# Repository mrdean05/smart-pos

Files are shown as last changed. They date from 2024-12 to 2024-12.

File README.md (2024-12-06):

<h2> Battery Powered Two-Layer PCB <h2>

__Note - This is an ongoing project__

## Introduction
This project describes the design and development of a battery-powered, two-layer PCB for a smart point-of-sale (POS) device. The smart point-of-sale device is intended to work with a barcode scanner, identifying items and products with barcode IDs. It comes with a TFT screen and a GUI displaying the product details, including the brand, type, weight, and cost.

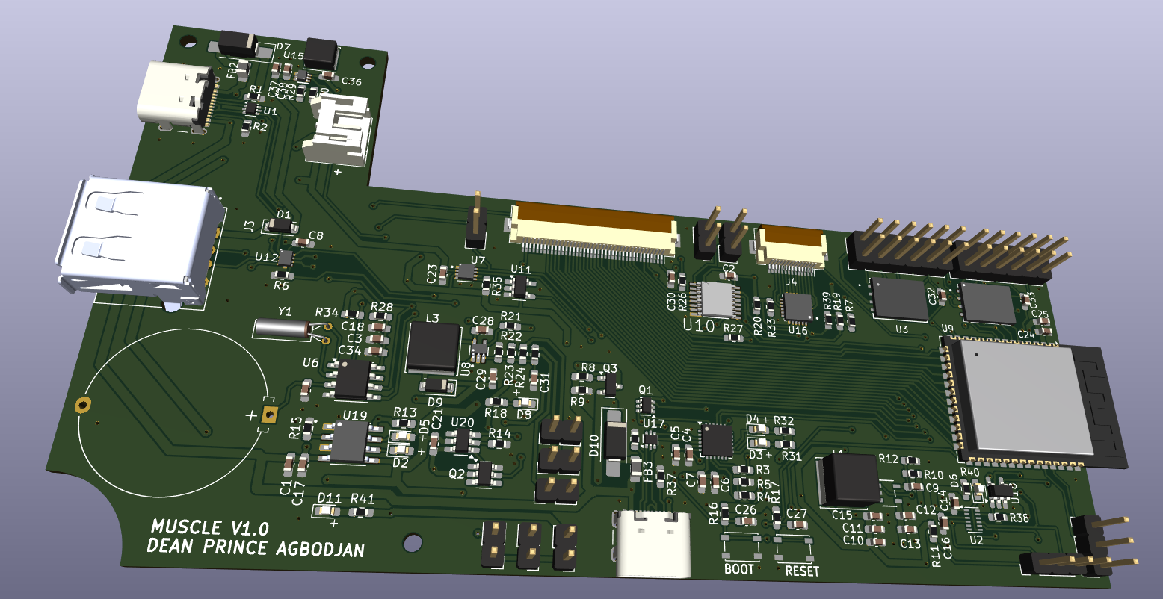
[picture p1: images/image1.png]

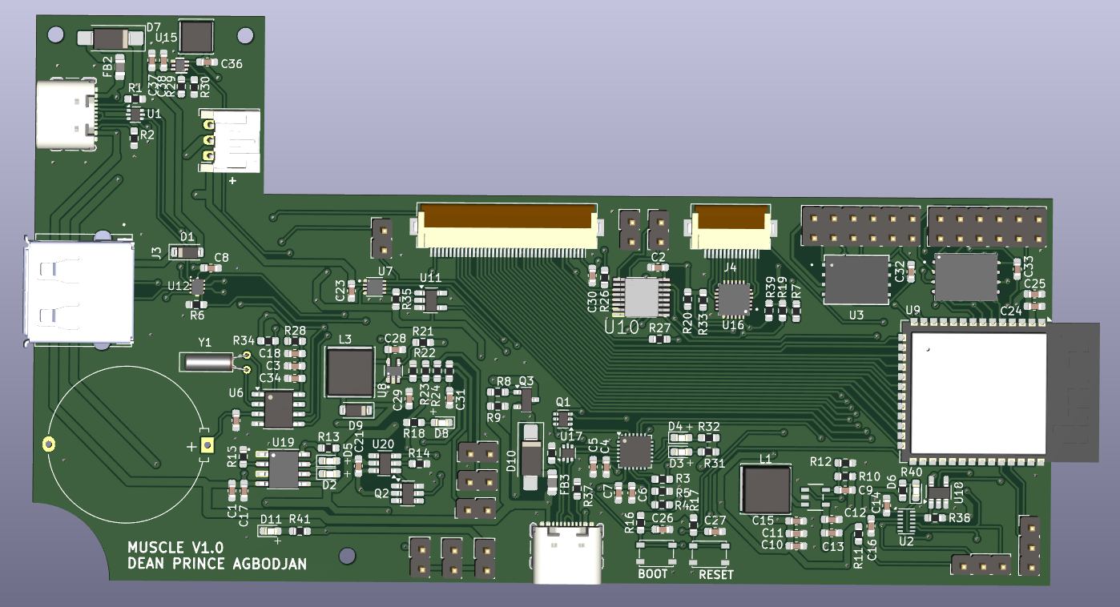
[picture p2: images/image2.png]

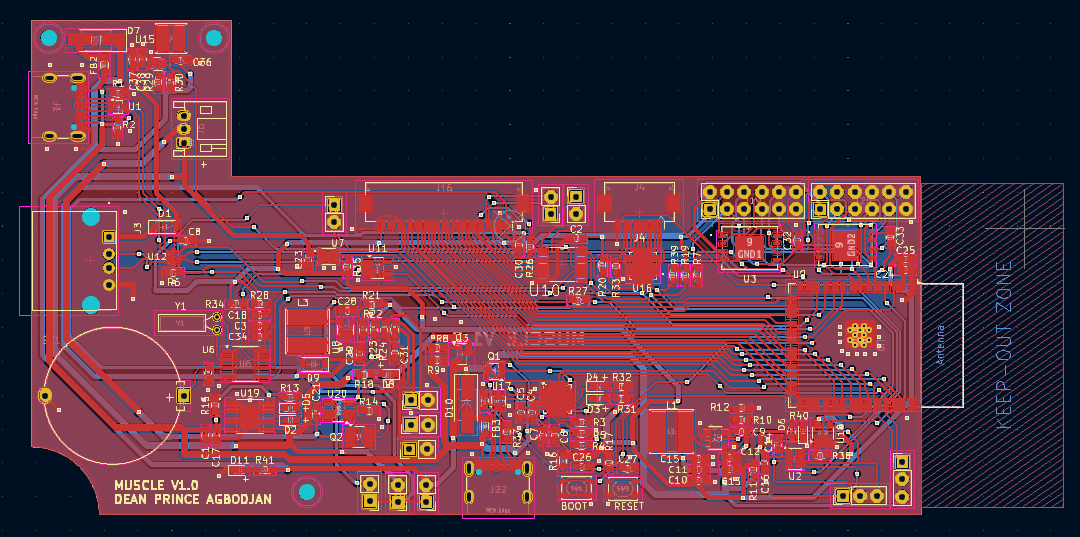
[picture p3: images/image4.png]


## Background of Project
There are numerous small to medium enterprises in Ghana that lack an effective way to track their inventory and finances. The existing implementations are very bulky and expensive, with software that is difficult for an average small shop owner to navigate, and with outrageous monthly subscriptions. This smart point-of-sale (POS) device seeks to simplify and improve the existing solution by creating a quick-to-use, cheap, and portable device. It works with a mobile application that updates the shop owner on every item bought in the shop, giving the shop owner visibility over their shop without their physical presence.

## Hardware and Circuit Design
The PCB was design and developed using KiCad. It comprises of multiple ICs (micocontroller, convertor ICs, and others).

* The Micrcontroller used is the ESP32s3. ESP32s3 is a System-On-Chip(SoC) integrating WiFi and Bluetooth, with peripherals that enable connection with other ICs and modules. 

* The PCBs also integrates ICs such
    - **SY8089 Buck Power Converter** that reduces the input voltage from 5V to 3.3V for the microcontroller and other components in the circuit. It has about 2A output current, with capacitors used as noise filters.
    - **TP4056 and DW01A** that ensure battery health safety by preventing under and over charging.
    - **MAX17048** as a current fuel gauge for the battery.
    - **PCF8523T** serves as an RTC module providing precise time and date information. It is supplied by a coin battery that ensures its continual performance when the device is off.
    - **TCA8418** serves as a keypad scan device through which users can interact with the POS device.
    - **W25N02KVZEIR and W25Q256JVEIQ** that serves as additional flash memory.
    - **PCA95548** serves as additional gpios.

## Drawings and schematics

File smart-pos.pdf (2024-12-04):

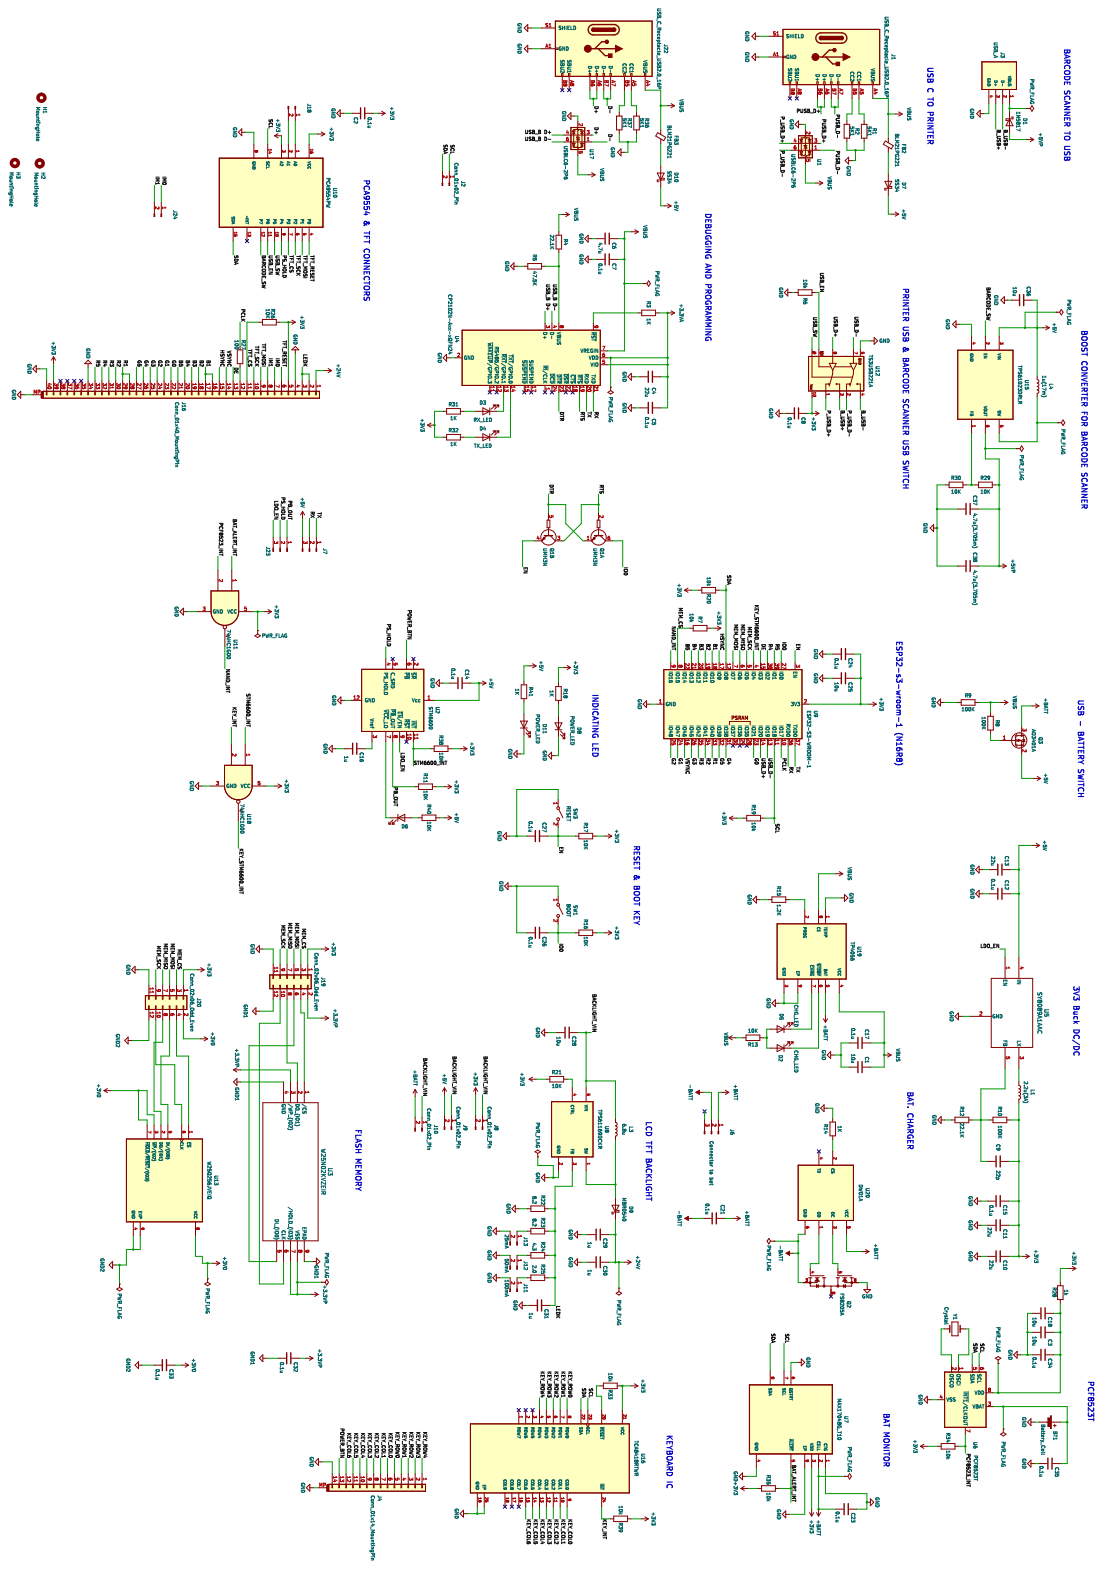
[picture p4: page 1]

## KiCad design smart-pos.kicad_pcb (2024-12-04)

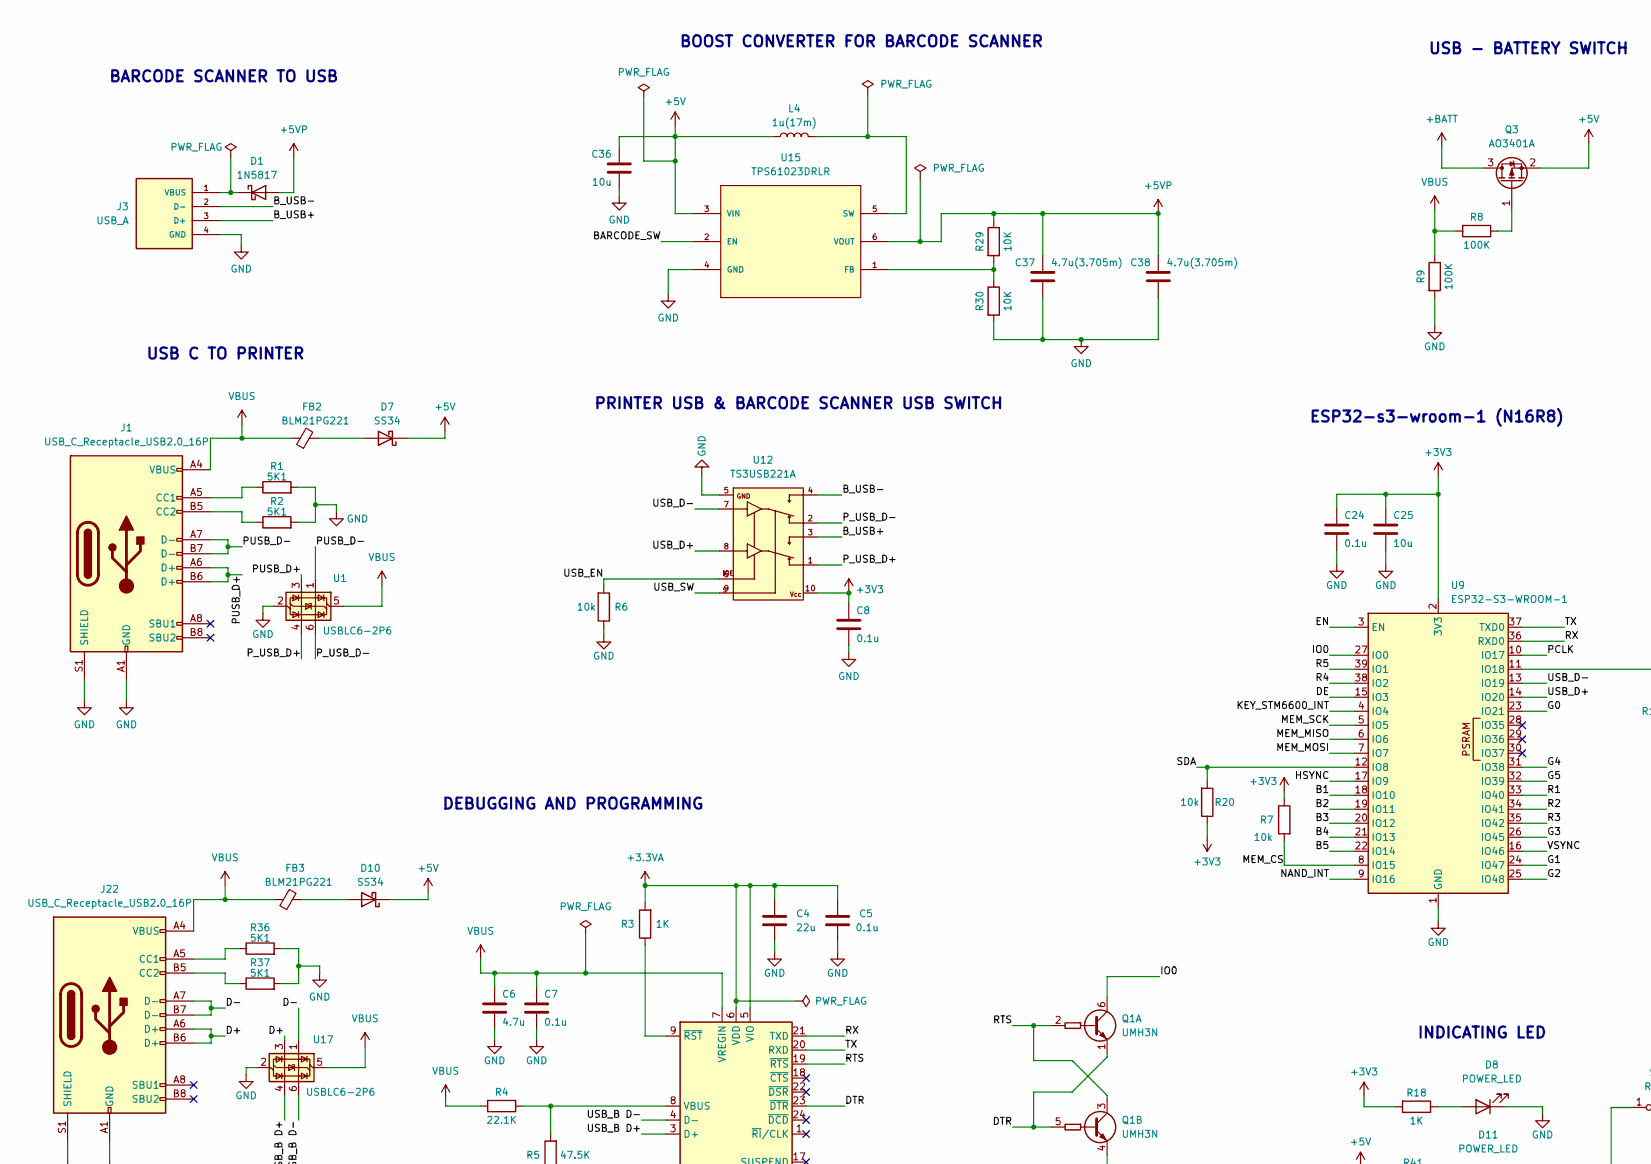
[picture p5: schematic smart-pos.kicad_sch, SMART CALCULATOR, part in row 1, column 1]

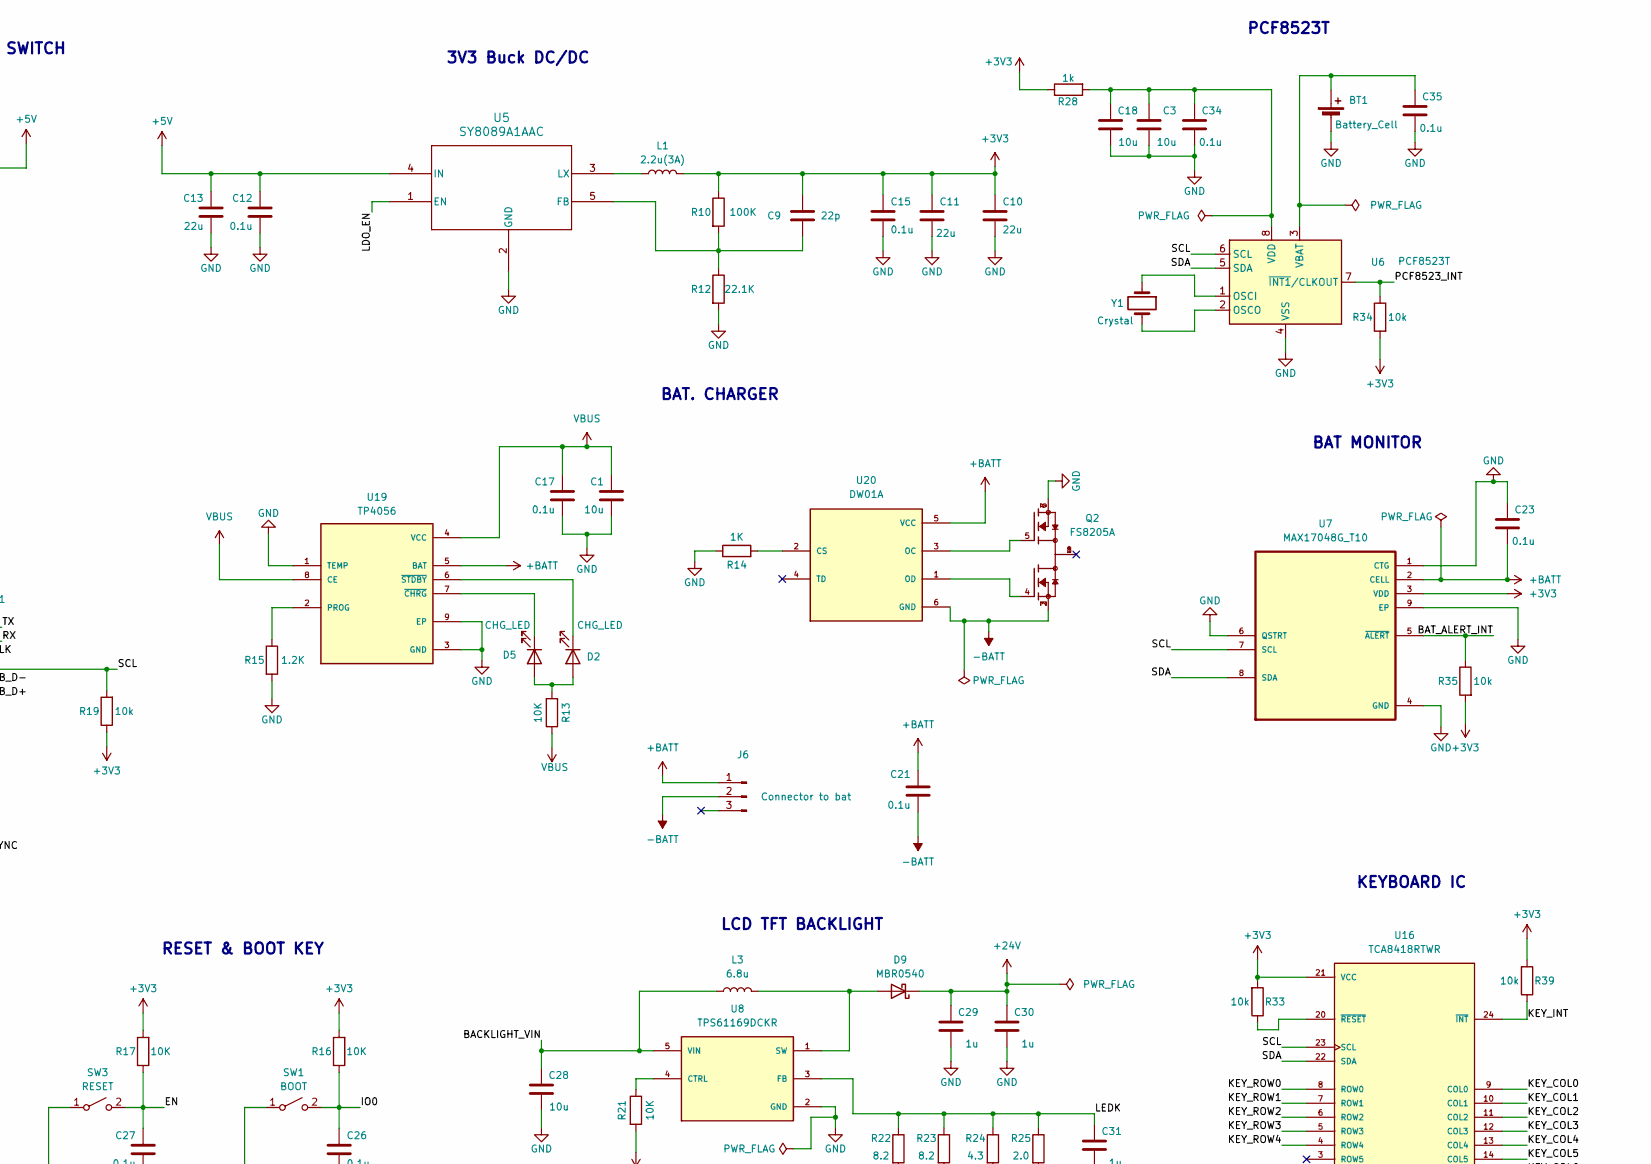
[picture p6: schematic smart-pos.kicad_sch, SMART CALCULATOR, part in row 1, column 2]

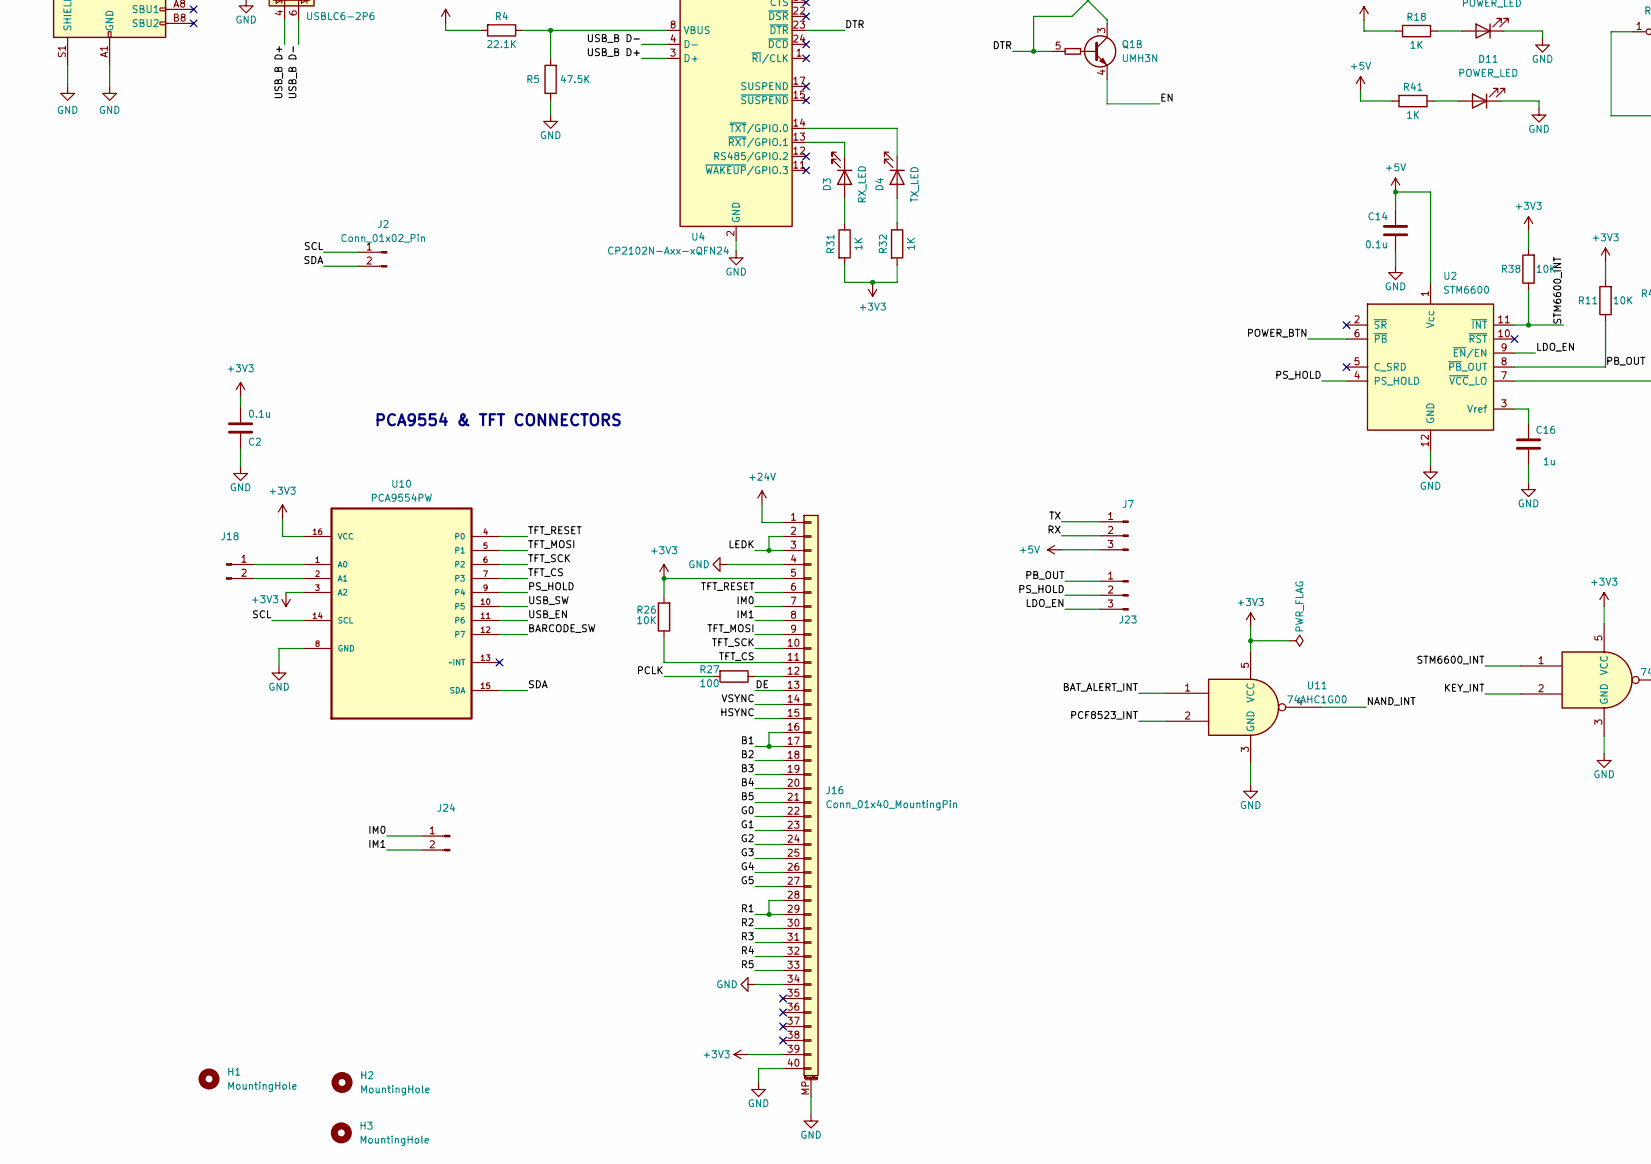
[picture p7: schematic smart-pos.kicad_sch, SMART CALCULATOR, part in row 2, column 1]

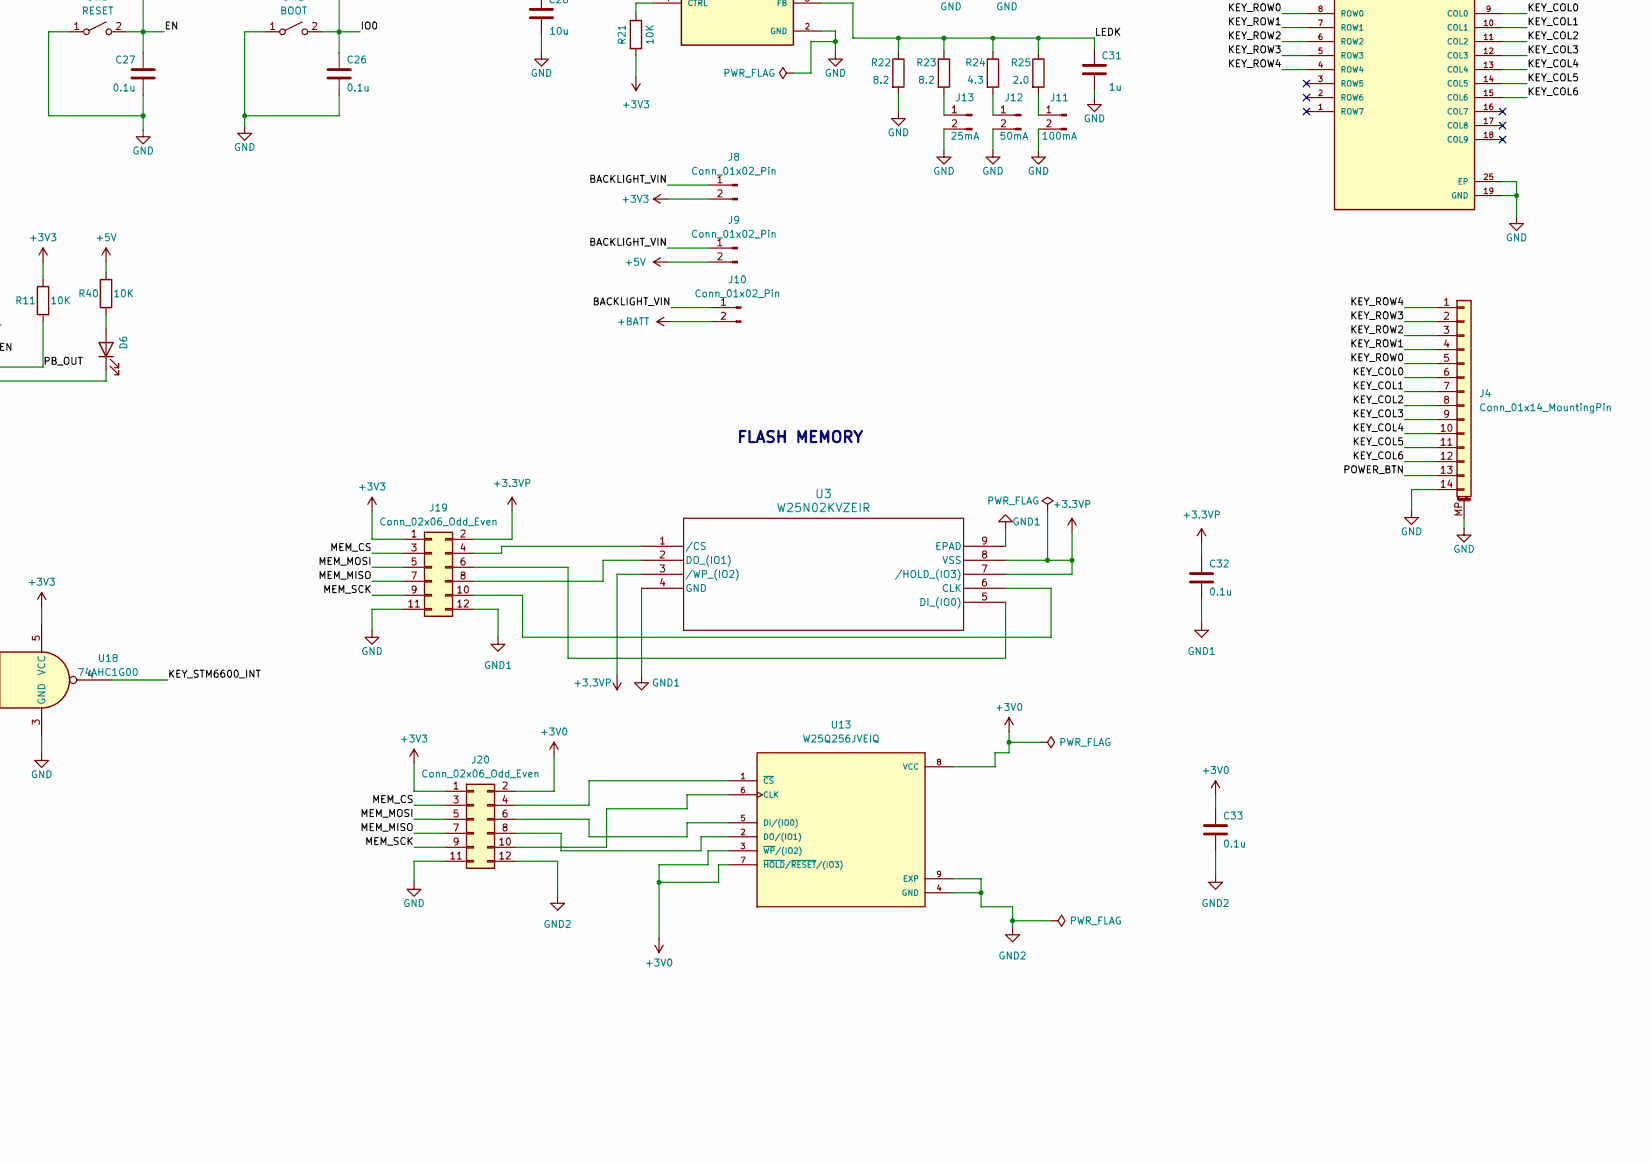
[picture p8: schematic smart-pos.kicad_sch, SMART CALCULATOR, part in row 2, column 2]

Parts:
BT1: Battery_Cell; Battery_Panasonic_CR2032-HFN_Horizontal_CircularHoles
C1, C3, C18, C25, C28, C36: 10u; C_0603_1608Metric_Pad1.08x0.95mm_HandSolder
C2, C5, C7, C8, C12, C14, C15, C17, C21, C23, C24, C26, C27, C32, C33, C34, C35: 0.1u; C_0603_1608Metric_Pad1.08x0.95mm_HandSolder
C4, C10, C11, C13: 22u; C_0603_1608Metric_Pad1.08x0.95mm_HandSolder
C6: 4.7u; C_0603_1608Metric_Pad1.08x0.95mm_HandSolder
C9: 22p; C_0603_1608Metric_Pad1.08x0.95mm_HandSolder
C16, C29, C30, C31: 1u; C_0603_1608Metric_Pad1.08x0.95mm_HandSolder
C37, C38: 4.7u(3.705m); C_0603_1608Metric_Pad1.08x0.95mm_HandSolder
D1: 1N5817; D_SOD-123
D2, D5: CHG_LED; LED_0603_1608Metric_Pad1.05x0.95mm_HandSolder
D3, D6: RX_LED; LED_0603_1608Metric_Pad1.05x0.95mm_HandSolder
D4: TX_LED; LED_0603_1608Metric_Pad1.05x0.95mm_HandSolder
D7, D10: SS34; D_SMA_Handsoldering
D8, D11: POWER_LED; LED_0603_1608Metric_Pad1.05x0.95mm_HandSolder
D9: MBR0540; D_SOD-123
FB2, FB3: BLM21PG221; L_0805_2012Metric_Pad1.05x1.20mm_HandSolder
H1, H2, H3: MountingHole; MountingHole_2.1mm
J1, J22: USB_C_Receptacle_USB2.0_16P; USB_C_Receptacle_GCT_USB4105-xx-A_16P_TopMnt_Horizontal
J2, J8, J9, J10, J18, J24: Conn_01x02_Pin; PinHeader_1x02_P2.54mm_Vertical
J3: USB_A; OST_USB-A1HSW6; PARTREV A
J4: Conn_01x14_MountingPin; Hirose_FH12-14S-0.5SH_1x14-1MP_P0.50mm_Horizontal
J6: Connector to bat; JST_PH_S3B-PH-K_1x03_P2.00mm_Horizontal
J7, J23: Connector to IM0; PinHeader_1x03_P2.54mm_Vertical
J11: 100mA; PinHeader_1x02_P2.54mm_Vertical
J12: 50mA; PinHeader_1x02_P2.54mm_Vertical
J13: 25mA; PinHeader_1x02_P2.54mm_Vertical
J16: Conn_01x40_MountingPin; Hirose_FH12-40S-0.5SH_1x40-1MP_P0.50mm_Horizontal
J19, J20: Conn_02x06_Odd_Even; PinHeader_2x06_P2.54mm_Vertical
L1: 2.2u(3A); L_Cenker_CKCS6045
L3: 6.8u; L_Cenker_CKCS6020
L4: 1u(17m); L_Cenker_CKCS4018
Q1: UMH3N; SOT-363_SC-70-6
Q2: FS8205A; SOT-23-6_Handsoldering; PARTREV 1.7
Q3: AO3401A; SOT-23
R1, R2, R36, R37: 5K1; R_0603_1608Metric_Pad0.98x0.95mm_HandSolder
R3, R14, R18, R31, R32, R41: 1K; R_0603_1608Metric_Pad0.98x0.95mm_HandSolder
R4, R12: 22.1K; R_0603_1608Metric_Pad0.98x0.95mm_HandSolder
R5: 47.5K; R_0603_1608Metric_Pad0.98x0.95mm_HandSolder
R6, R7, R19, R20, R33, R34, R35, R39: 10k; R_0603_1608Metric_Pad0.98x0.95mm_HandSolder
R8, R9, R10: 100K; R_0603_1608Metric_Pad0.98x0.95mm_HandSolder
R11, R13, R16, R17, R21, R26, R29, R30, R38, R40: 10K; R_0603_1608Metric_Pad0.98x0.95mm_HandSolder
R15: 1.2K; R_0603_1608Metric_Pad0.98x0.95mm_HandSolder
R22, R23: 8.2; R_0603_1608Metric_Pad0.98x0.95mm_HandSolder
R24: 4.3; R_0603_1608Metric_Pad0.98x0.95mm_HandSolder
R25: 2.0; R_0603_1608Metric_Pad0.98x0.95mm_HandSolder
R27: 100; R_0603_1608Metric_Pad0.98x0.95mm_HandSolder
R28: 1k; R_0603_1608Metric_Pad0.98x0.95mm_HandSolder
SW1: BOOT; SW_SPST_PTS810
SW3: RESET; SW_SPST_PTS810
U1, U17: USBLC6-2P6; SOT-666
U2: STM6600; TDFN-12_2x3mm_P0.5mm
U3: W25N02KVZEIR; W25N02-M
U4: CP2102N-Axx-xQFN24; QFN-24-1EP_4x4mm_P0.5mm_EP2.6x2.6mm
U5: SY8089A1AAC; SY8089AAAC_SGY
U6: PCF8523T; SOIC-8_3.9x4.9mm_P1.27mm
U7: MAX17048G_T10; SON50P200X200X80-9N
U8: TPS61169DCKR; SOT65P210X110-5N; PARTREV A
U9: ESP32-S3-WROOM-1
U10: PCA9554PW; SOP65P640X120-16N; MPN PCA9554PW
U11, U18: 74AHC1G00; SOT-23-5_HandSoldering
U12: TS3USB221A; QFN-10-RSE
U13: W25Q256JVEIQ; SON127P600X800X80-9N; PARTREV G
U15: TPS61023DRLR; DRL0006A; PARTNUMBER TPS61023DRL
U16: TCA8418RTWR; QFN50P400X400X80-25N; PARTREV G
U19: TP4056; SOP127P600X175-9N
U20: DW01A; SOT-23-6_Handsoldering; PARTREV 1.8
Y1: Crystal; Crystal_C26-LF_D2.1mm_L6.5mm_Horizontal

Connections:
+3.3VA: C4.1, C5.1, R3.2, U4.5 (VIO), U4.6 (VDD)
+3.3VP: C32.1, J19.2, U3.3 (/WP_(IO2)), U3.7 (/HOLD_(IO3)), U3.8 (VSS)
+3V0: C33.1, J20.2, U13.3 (~WP/(IO2)), U13.7 (~HOLD/~RESET/(IO3)), U13.8 (VCC)
+3V3: C2.2, C8.1, C9.1, C10.1, C11.1, C15.1, C24.1, C25.1, J8.2, J16.5, J16.39, J19.1, J20.1, L1.2, R7.1, R10.1, R11.2, R16.2, R17.2, R18.2, R19.1, R20.1, R21.2, R26.2, R28.1, R31.2, R32.2, R33.2, R34.2, R35.2, R38.2, R39.2, U7.3 (VDD), U9.2 (3V3), U10.3 (A2), U10.16 (VCC), U11.5 (VCC), U12.10, U16.21 (VCC), U18.5 (VCC)
+5V: C12.1, C13.1, C14.1, C36.1, D7.1 (K), D10.1 (K), J7.3, J9.2, L4.1, Q3.2 (S), R40.2, R41.2, U2.1 (Vcc), U5.4 (IN), U15.3 (VIN); also elsewhere on the board
+5VP: C37.1, C38.1, D1.2 (A), R29.1, U15.6 (VOUT)
+24V: C29.1, C30.1, D9.1 (K), J16.1
+BATT: C21.1, C23.2, J6.1, J10.2, Q3.3 (D), U7.2 (CELL), U19.5 (BAT), U20.5 (VCC)
-BATT: C21.2, J6.2, Q2.2, Q2.3, U20.6 (GND)
/B1: J16.16, J16.17, U9.18 (IO10)
/B2: J16.18, U9.19 (IO11)
/B3: J16.19, U9.20 (IO12)
/B4: J16.20, U9.21 (IO13)
/B5: J16.21, U9.22 (IO14)
/BACKLIGHT_VIN: C28.1, J8.1, J9.1, J10.1, L3.1, U8.5 (VIN)
/BARCODE_SW: U10.12 (P7), U15.2 (EN)
/BAT_ALERT_INT: R35.1, U7.5 (~ALERT), U11.1
/B_USB+: J3.3 (D+), U12.3
/B_USB-: J3.2 (D-), U12.4
/D+: J22.A6 (D+), J22.B6 (D+), U17.3 (I/O2)
/D-: J22.A7 (D-), J22.B7 (D-), U17.1 (I/O1)
/DE: J16.13, U9.15 (IO3)
/DTR: Q1.1 (E1), Q1.5 (B2), U4.23 (~DTR)
/EN: C27.1, Q1.4 (E2), R17.1, SW3.2 (B), U9.3 (EN)
/G0: J16.22, U9.23 (IO21)
/G1: J16.23, U9.24 (IO47)
/G2: J16.24, U9.25 (IO48)
/G3: J16.25, U9.26 (IO45)
/G4: J16.26, U9.31 (IO38)
/G5: J16.27, U9.32 (IO39)
/HSYNC: J16.15, U9.17 (IO9)
/IM0: J16.7, J24.1
/IM1: J16.8, J24.2
/IO0: C26.1, Q1.6 (C1), R16.1, SW1.2 (B), U9.27 (IO0)
/KEY_COL0: J4.6, U16.9 (COL0)
/KEY_COL1: J4.7, U16.10 (COL1)
/KEY_COL2: J4.8, U16.11 (COL2)
/KEY_COL3: J4.9, U16.12 (COL3)
/KEY_COL4: J4.10, U16.13 (COL4)
/KEY_COL5: J4.11, U16.14 (COL5)
/KEY_COL6: J4.12, U16.15 (COL6)
/KEY_INT: R39.1, U16.24 (~INT), U18.2
/KEY_ROW0: J4.5, U16.8 (ROW0)
/KEY_ROW1: J4.4, U16.7 (ROW1)
/KEY_ROW2: J4.3, U16.6 (ROW2)
/KEY_ROW3: J4.2, U16.5 (ROW3)
/KEY_ROW4: J4.1, U16.4 (ROW4)
/KEY_STM6600_INT: U9.4 (IO4), U18.4
/LDO_EN: J23.3, U2.9 (~EN/EN), U5.1 (EN)
/LEDK: C31.1, J16.2, J16.3, R22.1, R23.1, R24.1, R25.1, U8.3 (FB)
/MEM_CS: J19.3, J20.3, R7.2, U9.8 (IO15)
/MEM_MISO: J19.7, J20.7, U9.6 (IO6)
/MEM_MOSI: J19.5, J20.5, U9.7 (IO7)
/MEM_SCK: J19.9, J20.9, U9.5 (IO5)
/NAND_INT: U9.9 (IO16), U11.4
/PB_OUT: J23.1, R11.1, U2.8 (~PB_OUT)
/PCF8523_INT: R34.1, U6.7 (~INT1/CLKOUT), U11.2
/PCLK: R27.2, U9.10 (IO17)
/POWER_BTN: J4.13, U2.6 (~PB)
/PS_HOLD: J23.2, U2.4 (PS_HOLD), U10.9 (P4)
/PUSB_D+: J1.A6 (D+), J1.B6 (D+), U1.3 (I/O2)
/PUSB_D-: J1.A7 (D-), J1.B7 (D-), U1.1 (I/O1)
/P_USB_D+: U1.4 (I/O2), U12.1
/P_USB_D-: U1.6 (I/O1), U12.2
/R1: J16.28, J16.29, U9.33 (IO40)
/R2: J16.30, U9.34 (IO41)
/R3: J16.31, U9.35 (IO42)
/R4: J16.32, U9.38 (IO2)
/R5: J16.33, U9.39 (IO1)
/RTS: Q1.2 (B1), Q1.3 (C2), U4.19 (~RTS)
/RX: J7.2, U4.21 (TXD), U9.36 (RXD0)
/SCL: J2.1, R19.2, U6.6 (SCL), U7.7 (SCL), U9.11 (IO18), U10.14 (SCL), U16.23 (SCL)
/SDA: J2.2, R20.2, U6.5 (SDA), U7.8 (SDA), U9.12 (IO8), U10.15 (SDA), U16.22 (SDA)
/STM6600_INT: R38.1, U2.11 (~INT), U18.1
/TFT_CS: J16.11, R26.1, U10.7 (P3)
/TFT_MOSI: J16.9, U10.5 (P1)
/TFT_RESET: J16.6, U10.4 (P0)
/TFT_SCK: J16.10, U10.6 (P2)
/TX: J7.1, U4.20 (RXD), U9.37 (TXD0)
/USB_B D+: U4.3 (D+), U17.4 (I/O2)
/USB_B D-: U4.4 (D-), U17.6 (I/O1)
/USB_D+: U9.14 (IO20), U12.8
/USB_D-: U9.13 (IO19), U12.7
/USB_EN: R6.2, U10.11 (P6), U12.6
/USB_SW: U10.10 (P5), U12.9
/VSYNC: J16.14, U9.16 (IO46)
GND: BT1.2 (-), C1.2, C2.1, C3.2, C4.2, C5.2, C6.2, C7.2, C8.2, C10.2, C11.2, C12.2, C13.2, C14.2, C15.2, C16.2, C17.2, C18.2, C23.1, C24.2, C25.2, C26.2, C27.2, C28.2, C29.2, C30.2, C31.2, C34.2, C35.2, C36.2, C37.2, C38.2, D8.1 (K), D11.1 (K), J1.A1 (GND), J1.A12 (GND), J1.B1 (GND), J1.B12 (GND), J1.S1 (SHIELD), J3.4 (GND), J4.14, J4.MP (MountPin), J11.2, J12.2, J13.2, J16.4, J16.34, J16.40, J16.MP (MountPin), J19.11, J20.11, J22.A1 (GND), J22.A12 (GND), J22.B1 (GND), J22.B12 (GND), J22.S1 (SHIELD), Q2.6, Q2.7, R1.2, R2.2, R5.1, R6.1, R9.2, R12.2, R14.1, R15.2, R22.2, R30.2, R36.2, R37.2, SW1.1 (A), SW3.1 (A), U1.2 (GND), U2.12 (GND), U4.2 (GND), U4.25 (GND), U5.2 (GND), U6.4 (VSS), U7.1 (CTG), U7.4 (GND), U7.6 (QSTRT), U7.9 (EP), U8.2 (GND), U9.1 (GND), U9.40 (GND), U9.41 (GND), U10.8 (GND), U11.3 (GND), U12.5, U15.4 (GND), U16.19 (GND), U16.25 (EP), U17.2 (GND), U18.3 (GND), U19.1 (TEMP), U19.3 (GND), U19.9 (EP)
GND1: C32.2, J19.12, U3.4 (GND), U3.9 (EPAD)
GND2: C33.2, J20.12, U13.4 (GND), U13.9 (EXP)
unnamed: BT1.1 (+), C35.1, U6.3 (VBAT)
unnamed: D1.1 (K), J3.1 (VBUS)
unnamed: D2.2 (A), D5.2 (A), R13.2
unnamed: D2.1 (K), U19.6 (~STDBY)
unnamed: D3.2 (A), R31.1
unnamed: D3.1 (K), U4.13 (~RXT/GPIO.1)
unnamed: D4.2 (A), R32.1
unnamed: D4.1 (K), U4.14 (~TXT/GPIO.0)
unnamed: D5.1 (K), U19.7 (~CHRG)
unnamed: D6.2 (A), R40.1
unnamed: D6.1 (K), U2.7 (~VCC_LO)
unnamed: D7.2 (A), FB2.2
unnamed: D8.2 (A), R18.1
unnamed: D9.2 (A), L3.2, U8.1 (SW)
unnamed: D10.2 (A), FB3.2
unnamed: D11.2 (A), R41.1
unnamed: J1.A5 (CC1), R1.1
unnamed: J1.B5 (CC2), R2.1
unnamed: J11.1, R25.2
unnamed: J12.1, R24.2
unnamed: J13.1, R23.2
unnamed: J16.12, R27.1
unnamed: J18.1, U10.1 (A0)
unnamed: J18.2, U10.2 (A1)
unnamed: J19.4, U3.1 (/CS)
unnamed: J19.6, U3.5 (DI_(IO0))
unnamed: J19.8, U3.2 (DO_(IO1))
unnamed: J19.10, U3.6 (CLK)
unnamed: J20.4, U13.1 (~CS)
unnamed: J20.6, U13.5 (DI/(IO0))
unnamed: J20.8, U13.2 (DO/(IO1))
unnamed: J20.10, U13.6 (CLK)
unnamed: J22.A5 (CC1), R36.1
unnamed: J22.B5 (CC2), R37.1
unnamed: Q3.1 (G), R8.1
unnamed: C16.1, U2.3 (Vref)
unnamed: R4.1, R5.2, U4.8 (VBUS)
unnamed: R3.1, U4.9 (~RST)
unnamed: C9.2, R10.2, R12.1, U5.5 (FB)
unnamed: L1.1, U5.3 (LX)
unnamed: U6.1 (OSCI), Y1.1
unnamed: U6.2 (OSCO), Y1.2
unnamed: C3.1, C18.1, C34.1, R28.2, U6.8 (VDD)
unnamed: R21.1, U8.4 (CTRL)
unnamed: R29.2, R30.1, U15.1 (FB)
unnamed 134: L4.2, U15.5 (SW); also elsewhere on the board
unnamed: R33.1, U16.20 (~RESET)
unnamed: R15.1, U19.2 (PROG)
unnamed: R14.2, U20.2 (CS)
unnamed: Q2.5, U20.3 (OC)
unnamed: Q2.4, U20.1 (OD)
VBUS: C1.1, C6.1, C7.1, C17.1, FB2.1, FB3.1, J1.A4 (VBUS), J1.A9 (VBUS), J1.B4 (VBUS), J1.B9 (VBUS), J22.A4 (VBUS), J22.A9 (VBUS), J22.B4 (VBUS), J22.B9 (VBUS), R4.2, R8.2, R9.1, R13.1, U1.5 (VBUS), U4.7 (VREGIN), U17.5 (VBUS), U19.4 (VCC), U19.8 (CE)

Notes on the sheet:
FLASH MEMORY
DEBUGGING AND PROGRAMMING
PCA9554 & TFT CONNECTORS
3V3 Buck DC/DC
LCD TFT BACKLIGHT
USB - BATTERY SWITCH
USB C TO PRINTER
RESET & BOOT KEY
ESP32-s3-wroom-1 (N16R8)
BOOST CONVERTER FOR BARCODE SCANNER
INDICATING LED
PRINTER USB & BARCODE SCANNER USB SWITCH
PCF8523T
KEYBOARD IC
BAT. CHARGER
BAT MONITOR
BARCODE SCANNER TO USB

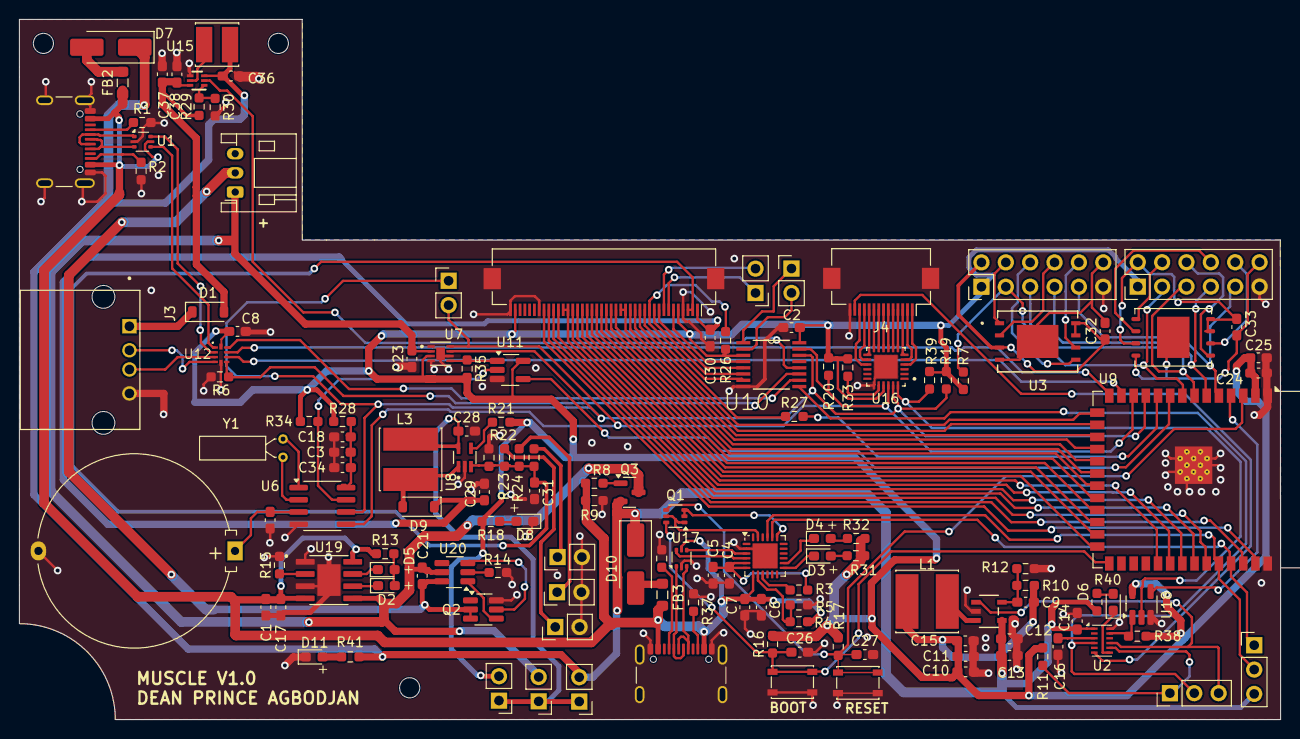
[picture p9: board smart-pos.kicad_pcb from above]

Board: 2 copper layers, 131.5 x 73.0 mm, 140 parts (0 on the bottom side), 141 nets.

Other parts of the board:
locked: 1u(17m); L_Cenker_CKCS4018

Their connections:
+5V: locked.1; also elsewhere on the board
unnamed 134: locked.2; also elsewhere on the board
